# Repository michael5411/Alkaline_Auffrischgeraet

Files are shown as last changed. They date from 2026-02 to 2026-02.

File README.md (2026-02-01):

TBild_1_Fertiges Gerät

The circuits "pumps" 12V pulsed voltage into your 1.5 V alkaline batteryuntil a threshold voltage is reached. This process is controlled by a ESP32 microprocessor. In this case an ESP32 D1 mini is used. 

An Arduino sketch with one main-program and four subfunctions is available here. The project is based on home assistant. Home Assistant is necessary for the MQTT-comunication and as display for the whole process. 
You may kick out this part of the sketch and use it without MQTT-communication and home assistant integration.
Be sure to edit the WiFi and MQTT-credentials according to your needs.

KiCAD-schematic and a proven PCB-layout are provided,too.

Standard operation is like this:

- you insert up to 4 AA batteries
- the acccording LEDs begin to flash and you see on your Home Assistant dashboard, that it shows the actual voltage of your batteries.
- fresh up takes place and stops, as soon as 1.65 volts are reached for a least 10 times. You may go for another threshold voltage, if you like.

- Some really weak batteries will never show 1.65 volts, but they will be ok for appropriate use anyway.

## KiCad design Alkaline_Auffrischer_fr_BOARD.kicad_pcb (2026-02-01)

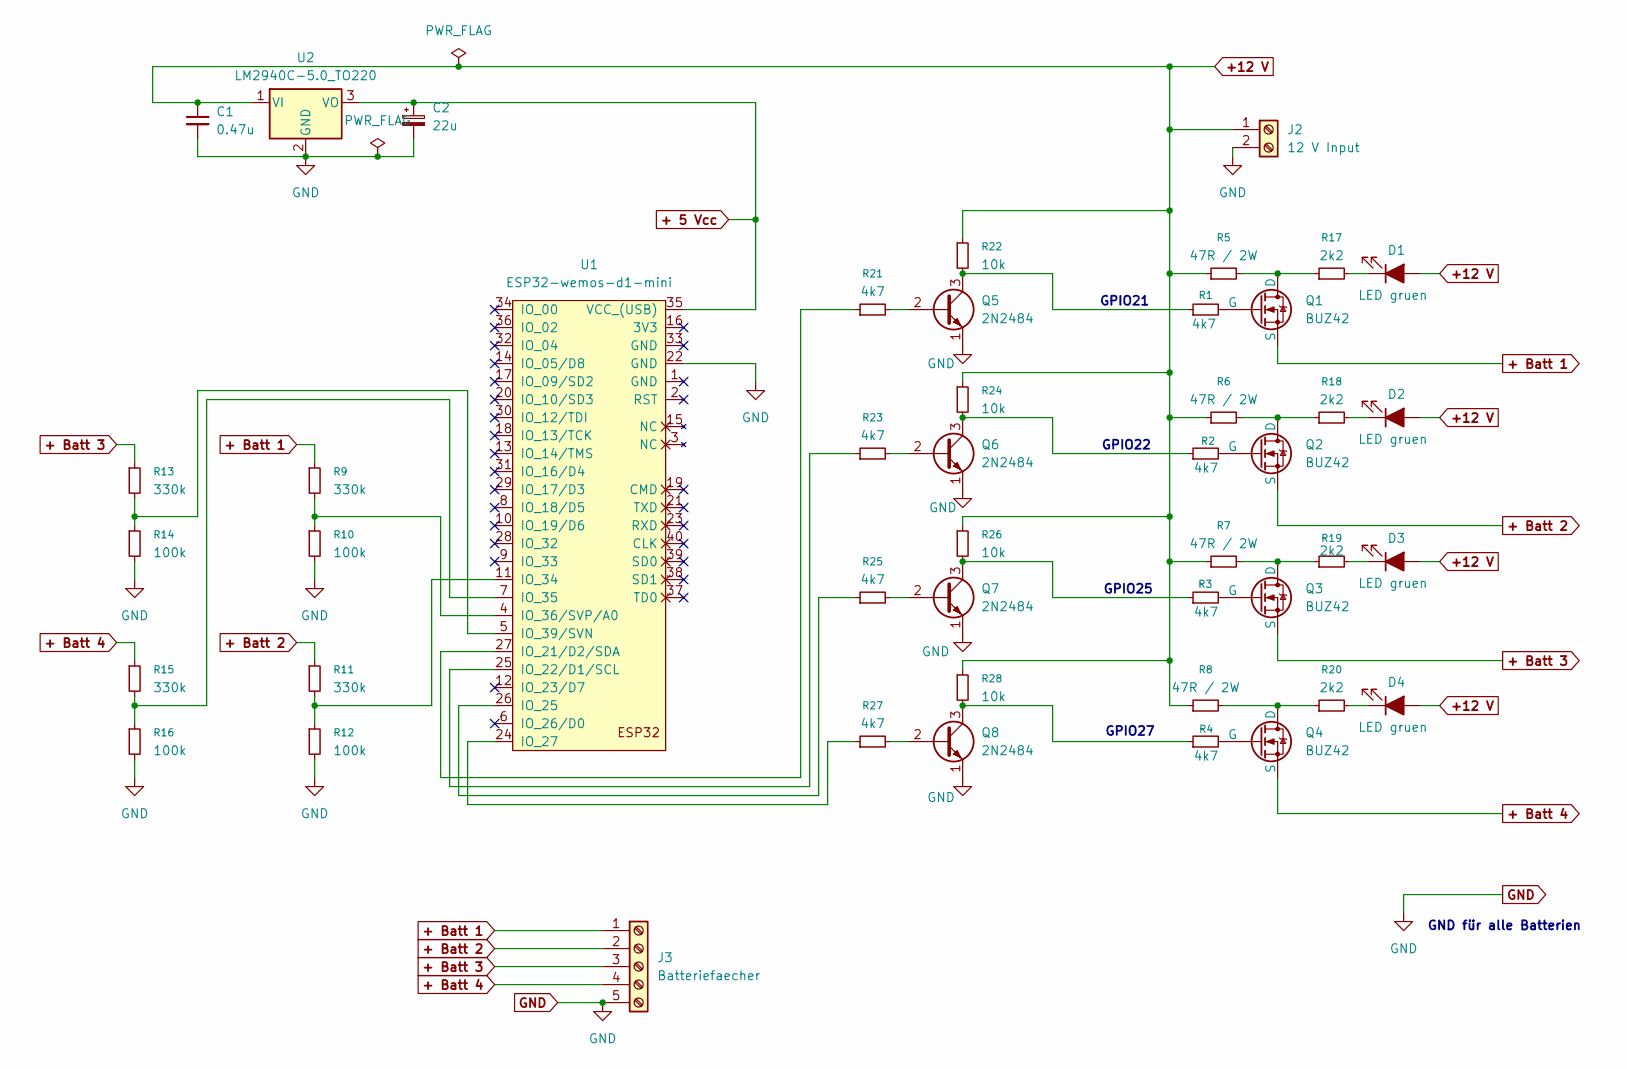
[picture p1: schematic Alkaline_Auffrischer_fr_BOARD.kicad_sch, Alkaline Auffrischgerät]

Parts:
C1: 0.47u; C_Axial_L3.8mm_D2.6mm_P7.50mm_Horizontal
C2: 22u; CP_Radial_D4.0mm_P1.50mm
D1, D2, D3, D4: LED gruen; LED_D5.0mm
J2: 12 V Input; TerminalBlock_MaiXu_MX126-5.0-02P_1x02_P5.00mm
J3: Batteriefaecher; TerminalBlock_MaiXu_MX126-5.0-05P_1x05_P5.00mm
Q1: BUZ42; TO-220-3_Vertical_1G2D3S
Q2, Q3, Q4: BUZ42
Q5, Q6, Q7, Q8: 2N2484; TO-18-3
R1, R2, R3, R4, R21, R23, R25, R27: 4k7; R_Axial_DIN0309_L9.0mm_D3.2mm_P12.70mm_Horizontal
R5, R6, R7, R8: 47R / 2W; R_Axial_DIN0414_L11.9mm_D4.5mm_P7.62mm_Vertical
R9, R11, R13, R15: 330k; R_Axial_DIN0309_L9.0mm_D3.2mm_P12.70mm_Horizontal
R10, R12, R14, R16: 100k; R_Axial_DIN0309_L9.0mm_D3.2mm_P12.70mm_Horizontal
R17, R18, R19, R20: 2k2; R_Axial_DIN0309_L9.0mm_D3.2mm_P12.70mm_Horizontal
R22, R24, R26, R28: 10k; R_Axial_DIN0309_L9.0mm_D3.2mm_P12.70mm_Horizontal
U1: ESP32-wemos-d1-mini; esp32-wemos-d1-mini
U2: LM2940C-5.0_TO220; TO-220F-3_Horizontal_TabDown

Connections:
+12 V: C1.1, D1.2 (A), D2.2 (A), D3.2 (A), D4.2 (A), J2.1, R5.1, R6.1, R7.1, R8.1, R22.1, R24.1, R26.1, R28.1, U2.1 (VI)
+ 5 Vcc: C2.1, U1.35 (VCC_(USB)), U2.3 (VO)
+ Batt 1: J3.1, Q1.3 (S), R9.1
+ Batt 2: J3.2, Q2.3 (S), R11.1
+ Batt 3: J3.3, Q3.3 (S), R13.1
+ Batt 4: J3.4, Q4.3 (S), R15.1
GND: C1.2, C2.2, J2.2, J3.5, Q5.1 (E), Q6.1 (E), Q7.1 (E), Q8.1 (E), R10.2, R12.2, R14.2, R16.2, U1.22 (GND), U2.2 (GND)
unnamed: D1.1 (K), R17.2
unnamed: D2.1 (K), R18.2
unnamed: D3.1 (K), R19.2
unnamed: D4.1 (K), R20.2
unnamed: Q1.2 (D), R5.2, R17.1
unnamed: Q1.1 (G), R1.2
unnamed: Q2.2 (D), R6.2, R18.1
unnamed: Q2.1 (G), R2.2
unnamed: Q3.2 (D), R7.2, R19.1
unnamed: Q3.1 (G), R3.2
unnamed: Q4.2 (D), R8.2, R20.1
unnamed: Q4.1 (G), R4.2
unnamed: Q5.2 (B), R21.2
unnamed: Q5.3 (C), R1.1, R22.2
unnamed: Q6.2 (B), R23.2
unnamed: Q6.3 (C), R2.1, R24.2
unnamed: Q7.2 (B), R25.2
unnamed: Q7.3 (C), R3.1, R26.2
unnamed: Q8.2 (B), R27.2
unnamed: Q8.3 (C), R4.1, R28.2
unnamed: R21.1, U1.27 (IO_21/D2/SDA)
unnamed: R23.1, U1.25 (IO_22/D1/SCL)
unnamed: R25.1, U1.26 (IO_25)
unnamed: R27.1, U1.24 (IO_27)
unnamed: R11.2, R12.1, U1.11 (IO_34)
unnamed: R15.2, R16.1, U1.7 (IO_35)
unnamed: R9.2, R10.1, U1.4 (IO_36/SVP/A0)
unnamed: R13.2, R14.1, U1.5 (IO_39/SVN)

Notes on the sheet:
GPIO22
GPIO27
GPIO21
GND für alle Batterien
GPIO25

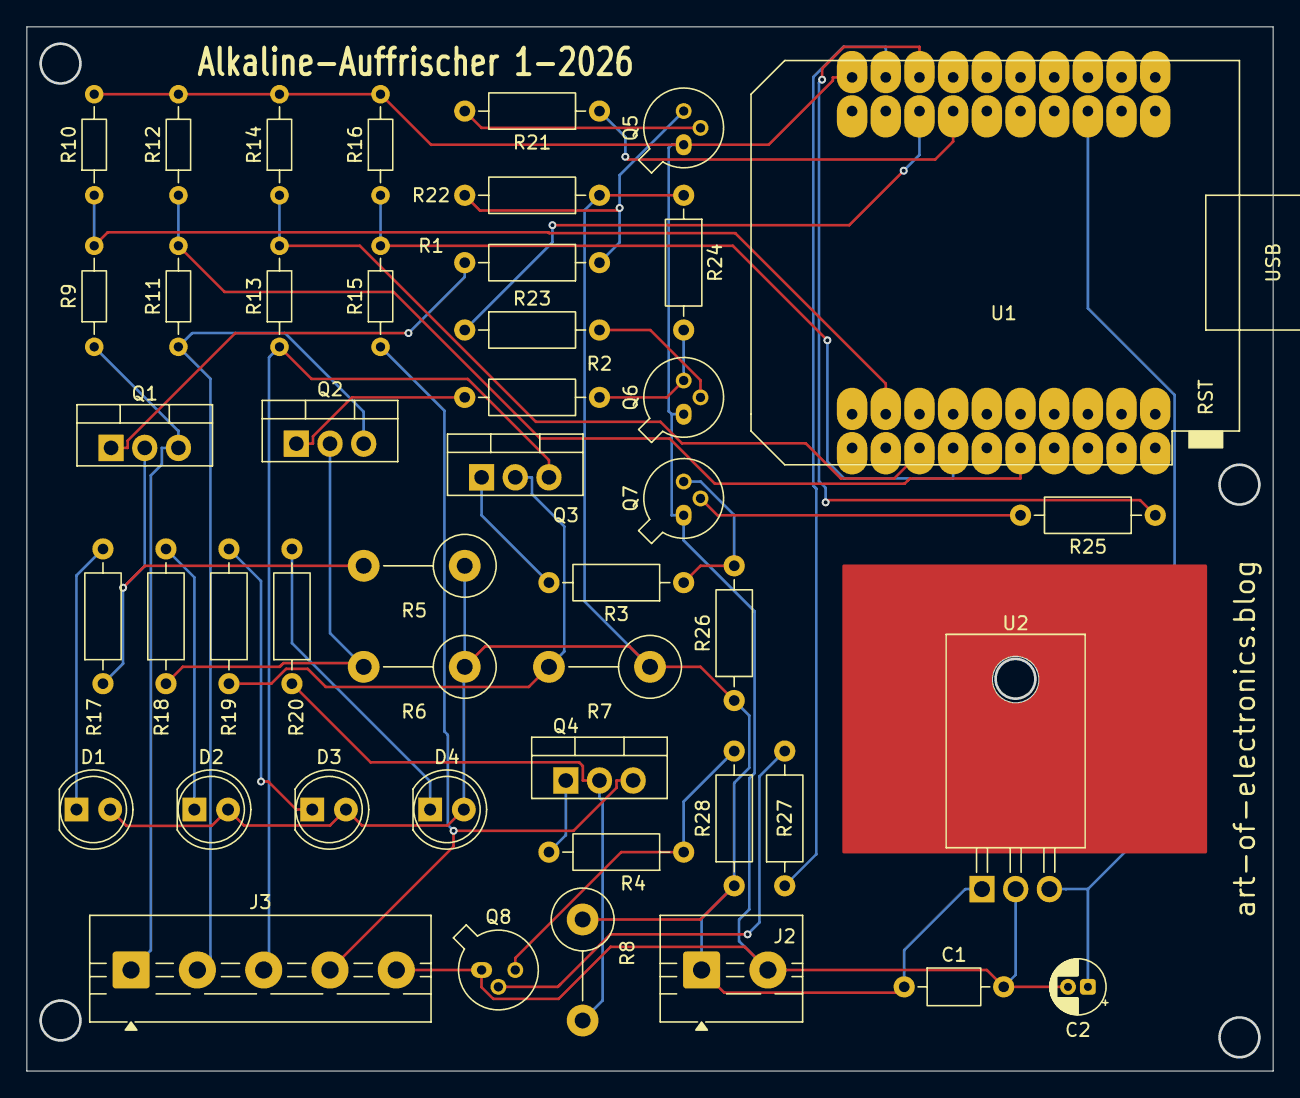
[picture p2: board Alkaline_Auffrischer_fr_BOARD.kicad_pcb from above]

Board: 2 copper layers, 94.0 x 78.7 mm, 46 parts (0 on the bottom side), 35 nets.

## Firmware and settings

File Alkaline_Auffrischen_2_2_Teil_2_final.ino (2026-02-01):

//Auffrischgerät für Alkaline-Batterien
//Michael Klein 1-2026 - Betriebsanleitung bitte beachten.

#include <WiFi.h>
#include <PubSubClient.h>
#include <string.h>

// ---------- Benutzer-Konfiguration ----------
const char* ssid       = "Meine SSID";
const char* wifi_pass  = "mein supersicheres Passwort";

IPAddress local_IP(192,168,0,58);
IPAddress gateway(192,168,0,1);
IPAddress subnet(255,255,255,0);
IPAddress primaryDNS(8,8,8,8);

const char* mqtt_server = "192.168.0.112";
const uint16_t mqtt_port = 1883;
const char* mqtt_user = "ESP32";
const char* mqtt_pass = "mein supersicheres MQTT-Passwort";

const char* mqtt_topic_batt1 = "mqttuser/aklader/batt1";
const char* mqtt_topic_batt2 = "mqttuser/aklader/batt2";
const char* mqtt_topic_batt3 = "mqttuser/aklader/batt3";
const char* mqtt_topic_batt4 = "mqttuser/aklader/batt4";
const char* mqtt_topic_batt1stat = "mqttuser/aklader/batt1stat";
const char* mqtt_topic_batt2stat = "mqttuser/aklader/batt2stat";
const char* mqtt_topic_batt3stat = "mqttuser/aklader/batt3stat";
const char* mqtt_topic_batt4stat = "mqttuser/aklader/batt4stat";

WiFiClient espClient;
PubSubClient client(espClient);

void connectMQTT();
void setupWiFiStatic();
void mqttPublishAll();
void messungen();
void printTable();
void statusmeldungen();

// ---------- Mess- / Lade-Variablen ----------
float battU[4] = {0.0, 0.0, 0.0, 0.0}; // Batteriespannungen 1 - 4
int battrawU[4] = {0, 0, 0, 0}; // Rohwerte der Batteriespannungen 1 - 4
int battload[4] = {10, 10, 10, 10}; // Anzahl der > Ulimit-Zustände
char battstat[4][16] = {
  "Keine Batt.",
  "Keine Batt.",
  "Keine Batt.",
  "Keine Batt."
  };
float Ulimit = 1.65; // Batteriespannung bis zu der geladen wird
float corr[4] ={1.0, 1.0, 1.0, 1.0}; //Korrekturwerte

int pwrPins[] = {21,22,25,27}; // Pins für Batterieladeimpulse
int messPins[] = {36,34,39,35}; //Pins der ADCs für Spannungsmessung

void setup() {
  Serial.begin(115200);

  for (int i=0; i<4; i++){ // I/O Ports für Pulser einstellen
    pinMode(pwrPins[i], OUTPUT);// I/O für Batterie [i]
    digitalWrite(pwrPins[i], HIGH); // Ladestrom aus
  }

  setupWiFiStatic();

  client.setServer(mqtt_server, mqtt_port);
  client.setCallback(nullptr); // nr ausgehende Topics in diesem Sketch
  connectMQTT();
}

void loop() {
  if (!client.connected()) {
    connectMQTT();
  }
  client.loop();

  messungen(); // Batteriespannungen messen

  for (int j=0; j<4; j++){ // Ladeimpuls, wenn Batterie vorhanden
    if(battU[j] < Ulimit && battU[j] > 0.2 && battload[j] > 0){
      digitalWrite(pwrPins[j], LOW); // Ladestrom einschalten
      delay(250); // Ladestrom 250 ms halten
    }
    digitalWrite(pwrPins[j], HIGH); // Ladestrom aus

    if(battU[j] == 0.0){
      battload[j] = 10; // Wenn Batterie fehlt oder gerade entnommen wurde
    }
    if(battU[j] >= Ulimit){
      battload[j] -= 1; // Wenn Ulimit erreicht wurde
    }
  } // Ende der for-Schleife
  
  statusmeldungen();

  // Publish nach Messungen und Status
  mqttPublishAll();

  if(battU[0]>= Ulimit || battU[1] >= Ulimit || battU[2] >= Ulimit || battU[3] >= Ulimit){
    printTable();
  }
  
  // 1 s Pause, um die Batterien zu schonen
  delay(1000);
}

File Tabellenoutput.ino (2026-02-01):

// Hilfsfunktion: gibt eine Fließkommazahl im Format X.YY aus
void printFixedXY(float v) {
  // positive Werte
  int whole = (int)v;
  int frac = (int)round((v - whole) * 100.0);
  if (frac == 100) { // Rundungsrandfall, z.B. 1.999 -> 2.00
    whole += 1;
    frac = 0;
  }
  // führende Null bei frac, falls nötig
  if (frac < 10) {
    Serial.print(whole);
    Serial.print('.');
    Serial.print('0');
    Serial.print(frac);
  } else {
    Serial.print(whole);
    Serial.print('.');
    Serial.print(frac);
  }
}

// Baut und druckt die Tabelle
void printTable() {
  Serial.println();
  Serial.println("       --- Batteriespannungen --- ");
  Serial.println();

  // Kopfzeile mit Spaltennummern (breite 9 pro Spalte, anpassbar)
  const int colWidth = 9;
  Serial.print(" "); // Ausrichtung
  for (int i = 0; i < 4; i++) {
    int pad = colWidth - 1; // eine Position für Abstand
    String s = String(i + 1);
    int leftSpaces = pad - s.length();
    for (int j = 0; j < leftSpaces; j++) Serial.print(' ');
    Serial.print(s);
  }
  Serial.println();
  Serial.println();

  // Wertezeile: jede Zahl rechtsbündig in der Spaltenbreite
  for (int i = 0; i < 4; i++) {
    // formatiere Wert in temporären String
    String tmp;
    {
      int whole = (int)battU[i];
      int frac = (int)round((battU[i] - whole) * 100.0);
      if (frac == 100) { whole += 1; frac = 0; }
      if (frac < 10) tmp = String(whole) + ".0" + String(frac);
      else tmp = String(whole) + "." + String(frac);
    }
    // rechtsbündig in colWidth
    int pad = colWidth - tmp.length();
    for (int j = 0; j < pad; j++) Serial.print(' ');
    Serial.print(tmp);
  }
  Serial.println();
}

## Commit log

2026-02-01 Add README content for battery management project
    Added project description and operational details for battery management system.
2026-02-01 KiCAD 9.0.7 Files
    [Alkaline_Auffrischer_fr_BOARD.kicad_pcb, Alkaline_Auffrischer_fr_BOARD.kicad_sch]
2026-02-01 Arduino files C++
